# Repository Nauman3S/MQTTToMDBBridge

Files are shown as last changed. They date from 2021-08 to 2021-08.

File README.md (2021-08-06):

# MQTT To MDB Bridge
## Atmega2560 Code(Arduino Mega)

## Pre Requirements
 
 The following should be installed in your PC
 
  - AVR-GCC
  - AVRDUDE
  - avr-libc

### Installing Pre-Reqs on Linux(Ubuntu or Debian Based Distro)

  On Ubuntu or any Debian based Linux distro execute the following commands
  - ```sudo apt-get install -y gcc-avr```
  - ```sudo apt-get install -y avrdude```
  - ```sudo apt-get install avr-libc```

### Setup

  1. Open terminal in the atmega2560FW folder and execute `make clean`
  2. Open makefile, replace P=COM1 to the COM port of your arduino mega and save the file
    1. Compile it with `make all`
  3. Upload it to your Arduino with `make program`

## ESP32 Code
## Pre Requirements

You should have Arduino IDE Installed

  1.  Add ESP32 Board to your Arduino IDE
    1. In your Arduino IDE, go to File> Preferences
        Installing ESP32 Add-on in Arduino IDE Windows, Mac OS X, Linux open preferences
    2. Enter ```https://dl.espressif.com/dl/package_esp32_index.json``` into the “Additional Board Manager URLs” field then, click the “OK” button:
    Note: if you already have the ESP8266 boards URL, you can separate the URLs with a comma as follows:
    ```https://dl.espressif.com/dl/package_esp32_index.json,
      http://arduino.esp8266.com/stable/package_esp8266com_index.json```
    3. Open the Boards Manager. Go to Tools > Board > Boards Manager…
    4. Search for ESP32 and press install button for the “ESP32 by Espressif Systems“:
    5. That’s it. It should be installed after a few seconds.

  2.  Now copy the contents of the libs folder to the libraries directory of your Arduino
    1. If you are using windows, the libraries directory will be Documents/Arduino/libraries
  3.  Select ESP32 Dev Kit from Tools->Board->ESP32 Dev Kit
  4.  Select the correct port from Tools->Port
  5.  Then in ESP32FW.ino file, on line number 13 and 14, put your WiFi creds
  6.  Upload the Code to your ESP32

  ```diff
  + broker used is borker.hivemq.com
  + vending can be done by publishing an ammount to mdb/invoke topic
  ```
  Note: for more details, you can see MQTTHandler.h file

## Circuit Diagram
Short Wire A and Wire B to start the MDB communication or put an on/off button
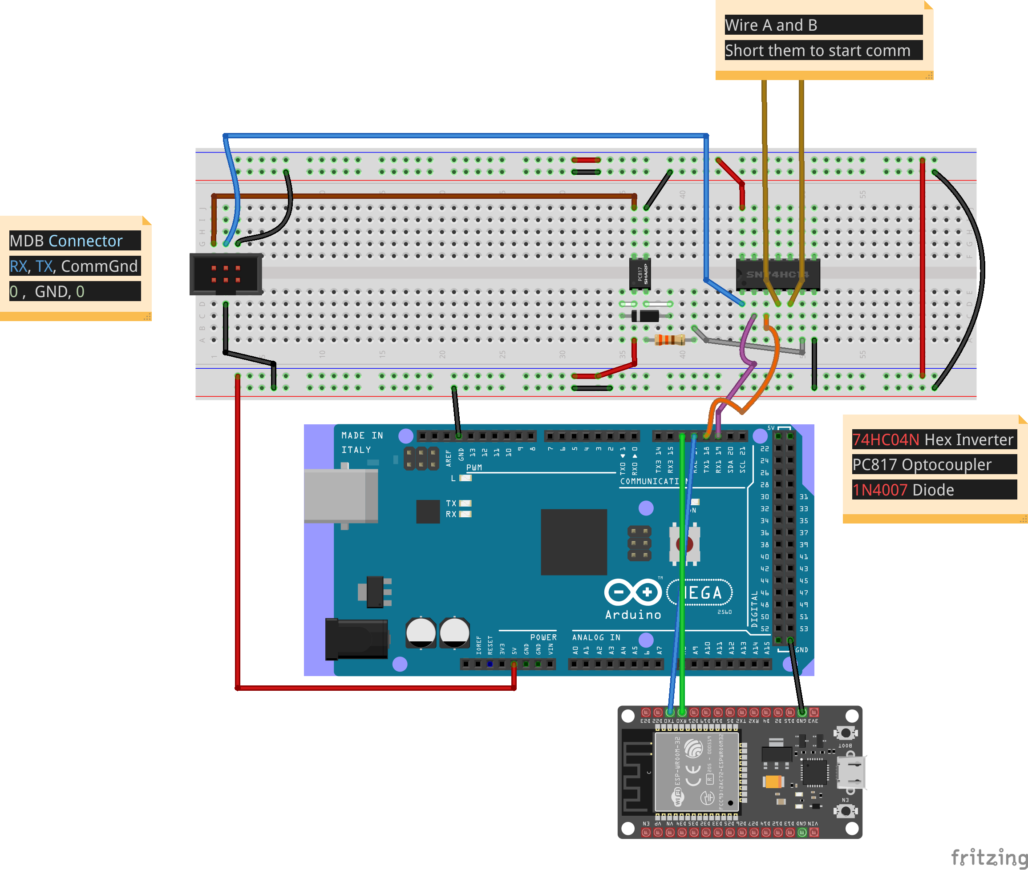
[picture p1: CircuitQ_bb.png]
GitHub Logo


The parts used in this circuit are:

* Optocoupler __OHPC 817C F919G__
* * [Datasheet](https://www.farnell.com/datasheets/73758.pdf)
* Schimitt Trigger Hex Inverter __PHILIPS 74HC14N B9784PS Hnn9840 E__
* * [Datasheet](https://datasheet.octopart.com/74HC14N-Philips-datasheet-7274161.pdf)
* Diode __1N4007 MIC AXIAL SILASTIC GUARD JUNCTION STANDARD RECTIFIER__
* * [Datasheet](https://rdd-tech.com/sites/default/files/attachment/1N4007%20MIC.pdf)
* Resistor 330 ohms
* Arduino Mega 2560
* ESP32 Dev Kit

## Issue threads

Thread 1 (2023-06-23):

How to deal with inverted tx from VMC

note5, 2023-06-23:
Hi,

I would like to know if your vending machine controller has inverted TX? if so how does this code handle it?

I start the vending machine the I see reseting  on the terminal until I get error

Error: invalid checksum [SETUP]
data[5]: 0x000013 ;;checksum-calc: 0x000013
ACK00
data[5]: 0x000010 ;;checksum-calc: 0x000010

What could be causing this?

Nauman3S, 2023-06-23:
@note5 Hi, this is not a well-maintained project and may have some outdated information. There are a couple of solutions to the inverted TX. The easiest one is to use a physical hex inverter or a buffer IC with an inverted output.

The software-based approach could be:

1) Try inverting hex values in the firmware
`    unsigned int hex;
     int inverted_hex=~hex;
`
and use `inverted_hex` everywhere.

2) Use a logic analyzer, record the TX, and RX values of a session and modify the firmware accordingly. This is the recommended approach as it allows fast debugging.

note5, 2023-06-23:
Thanks for the reply, I am am using a Godrej Tea vending dispenser. In the circuit it shows mdb as follows;

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

Will this change te circuit? I see the NAMA protocol is still at version 4.2 meaning the code is still valid

Nauman3S, 2023-06-23:
For a hardware-wise approach, you would need to put a hex inverter on the TX line with ground common to the MCU.

note5, 2023-06-23:
If I am getting this correctly, does it mean I pass the mdb tx through another  inverter if the 7414  (I have already replicated your fritzing circuit)

So instead of one inversions as currently is I add the output of the tx through another inverter before feeding it to the atmega2560's rx1 pin?
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

Nauman3S, 2023-06-23:
No, there will only be one hex inverter. You can simplify the circuit by removing the brown wires. The circuit should invert the signal only once. The circuit above is a bit confusing so it's better to ignore how hex inverter is placed in the circuit.

note5, 2023-06-23:
How would it look like? I am  a bit lost

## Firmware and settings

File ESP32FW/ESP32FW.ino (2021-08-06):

#include <WiFi.h>
#include <PubSubClient.h>

#include "constsV.h"
#include "SStack.h"
#include "MDBHandler.h"
#include "MQTTHandler.h"

#define BUILTIN_LED 2
// Update these with values suitable for your network.
const char* ssid = "YOUR WIFI NAME";
const char* password = "YOUR WIFI PASSWORD";


const char* mqtt_server = "broker.hivemq.com";

WiFiClient espClient;
PubSubClient client(espClient);
unsigned long lastMsg = 0;
#define MSG_BUFFER_SIZE  (50)
char msg[MSG_BUFFER_SIZE];
int value = 0;


void setup_wifi() {

  delay(10);
  // We start by connecting to a WiFi network
  Serial.println();
  Serial.print("Connecting to ");
  Serial.println(ssid);

  WiFi.mode(WIFI_STA);
  WiFi.begin(ssid, password);

  while (WiFi.status() != WL_CONNECTED) {
    delay(500);
    Serial.print(".");
  }

  randomSeed(micros());

  Serial.println("");
  Serial.println("WiFi connected");
  Serial.println("IP address: ");
  Serial.println(WiFi.localIP());
}

void callback(char* topic, byte* payload, unsigned int length) {
  Serial.print("Message arrived [");
  Serial.print(topic);
  Serial.print("] ");
  String payloadV="";
  for (int i = 0; i < length; i++) {
    Serial.print((char)payload[i]);
    payloadV=payloadV+String((char)payload[i]);
  }
  Serial.println();
  if(String(topic)==String(resetMDBT)){
    resetMDB();//reset MDB devices
  }
  if(String(topic)==String(MDBState)){
    mdbState();
    String res="Commiting MDBState";
    publishValues(String(responseV),res);
  }
  if(String(topic)==String(MDBInfo)){
    mdbState();
    String res="Commiting MDBInfo";
    publishValues(String(responseV),res);
  }

  if(String(topic)==String(invokeVendT)){
    
    String res="Invoking vend with ammount " + payloadV;
    vendInvoker(payloadV, "0","1");//invoke vend with ammount
    publishValues(String(responseV),res);
  }

  if(String(topic)==String(startSessionT)){
    
    String res="Starting session with ammount " + payloadV;
    startSession(payloadV);
    publishValues(String(responseV),res);
  }
  if(String(topic)==String(approveVendT)){
    
    String res="Approving session with ammount " + payloadV;
    approveVend(payloadV);
    publishValues(String(responseV),res);
    
  }
  if(String(topic)==String(cancelSessionT)){
    
    String res="Cancelling session";
    cancelSession();
    publishValues(String(responseV),res);
  }
  
  // Switch on the LED if an 1 was received as first character
  if ((char)payload[0] == '1') {
    digitalWrite(BUILTIN_LED, LOW);   // Turn the LED on (Note that LOW is the voltage level
    // but actually the LED is on; this is because
    // it is active low on the ESP-01)
  } else {
    digitalWrite(BUILTIN_LED, HIGH);  // Turn the LED off by making the voltage HIGH
  }

}

void publishValues(String topic, String msg){
      client.publish(topic.c_str(), msg.c_str()); 
}

void reconnect() {
  // Loop until we're reconnected
  while (!client.connected()) {
    Serial.print("Attempting MQTT connection...");
    // Create a random client ID
    String clientId = "ESP8266Client-";
    clientId += String(random(0xffff), HEX);
    // Attempt to connect
    if (client.connect(clientId.c_str())) {
      Serial.println("connected");
      MQTTstatus=1;
      // Once connected, publish an announcement...
      
      // ... and resubscribe
      client.subscribe(resetMDBT);
      client.subscribe(MDBState);
      client.subscribe(MDBInfo);
      client.subscribe(invokeVendT);
      client.subscribe(cancelSessionT);
      client.subscribe(startSessionT);
      client.subscribe(approveVendT);
      
    } else {
      Serial.print("failed, rc=");
      Serial.print(client.state());
      Serial.println(" try again in 5 seconds");
      // Wait 5 seconds before retrying
      delay(5000);
    }
  }
}

void setup() {
  pinMode(BUILTIN_LED, OUTPUT);     // Initialize the BUILTIN_LED pin as an output
  //setupADC();
  setupMDB();
  Serial.print("WiFi ST Mac: ");
  MAC=String(WiFi.macAddress());
  Serial.begin(115200);
  setup_wifi();
  client.setServer(mqtt_server, 1883);
  client.setCallback(callback);
}

void loop() {

  if (!client.connected()) {
    reconnect();
  }
  client.loop();

  checkResponse();
  String gR=getResponse();
  if(gR!=String("null")){
    
    String res=gR;//"@IO: HIGH*";
    publishValues(String(responseV),res);
    if(gR.indexOf("vend-success")>=0){
      
       Serial.println("Vend Successful");
       
    }
    if(gR.indexOf("vend-failed")>=0){

      Serial.println("Vend Failed");
      
    }

  }


  unsigned long now = millis();
  if (now - lastMsg > 2000) {//data update frequency == 2000mSec or 2sec
    lastMsg = now;

    // put normal processing code here
    
  }
}
